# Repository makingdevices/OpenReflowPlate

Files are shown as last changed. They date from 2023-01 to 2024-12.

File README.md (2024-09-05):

<!-- Improved compatibility of back to top link: See: https://github.com/othneildrew/Best-README-Template/pull/73 -->

<!--
*** Thanks for checking out the Best-README-Template. If you have a suggestion
*** that would make this better, please fork the repo and create a pull request
*** or simply open an issue with the tag "enhancement".
*** Don't forget to give the project a star!
*** Thanks again! Now go create something AMAZING! :D
-->

<!-- PROJECT SHIELDS -->
<!--
*** I'm using markdown "reference style" links for readability.
*** Reference links are enclosed in brackets [ ] instead of parentheses ( ).
*** See the bottom of this document for the declaration of the reference variables
*** for contributors-url, forks-url, etc. This is an optional, concise syntax you may use.
*** https://www.markdownguide.org/basic-syntax/#reference-style-links
-->
[][ig-url]
[][sponsor-url]
[][stars-url]
[][issues-url]
[][linkedin-url]

<!-- PROJECT LOGO -->
<br />
<div align="center">
  <a href="https://makingdevices.com/links/">
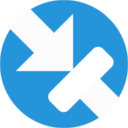
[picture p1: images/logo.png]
    
  </a>

<h3 align="center">Making Devices</h3>

  <p align="center">
    Open Source projects where we struggle with engineering, electronics, coding and who knows what else... In this case, OpenReflowPlate is a simple reflow plate for SMD PCBs, so hopefully you may find it interesting ;)
  </p>
</div>

<!-- TABLE OF CONTENTS -->
<details>
  <summary>Table of Contents</summary>
  <ol>
    <li>
      <a href="#about-the-project">About The Project</a>
      <ul>
        <li><a href="#built-with">Built With</a></li>
      </ul>
    </li>
    <li>
      <a href="#Build-one">Build one</a>
      <ul>
      </ul>
    </li>
    <li><a href="#usage">Usage</a></li>
    <li><a href="#roadmap">Roadmap</a></li>
    <li><a href="#license">License</a></li>
    <li><a href="#contact">Contact</a></li>
    <li><a href="#Sponsor">Sponsor</a></li>
  </ol>
</details>

<!-- ABOUT THE PROJECT -->
## About The Project

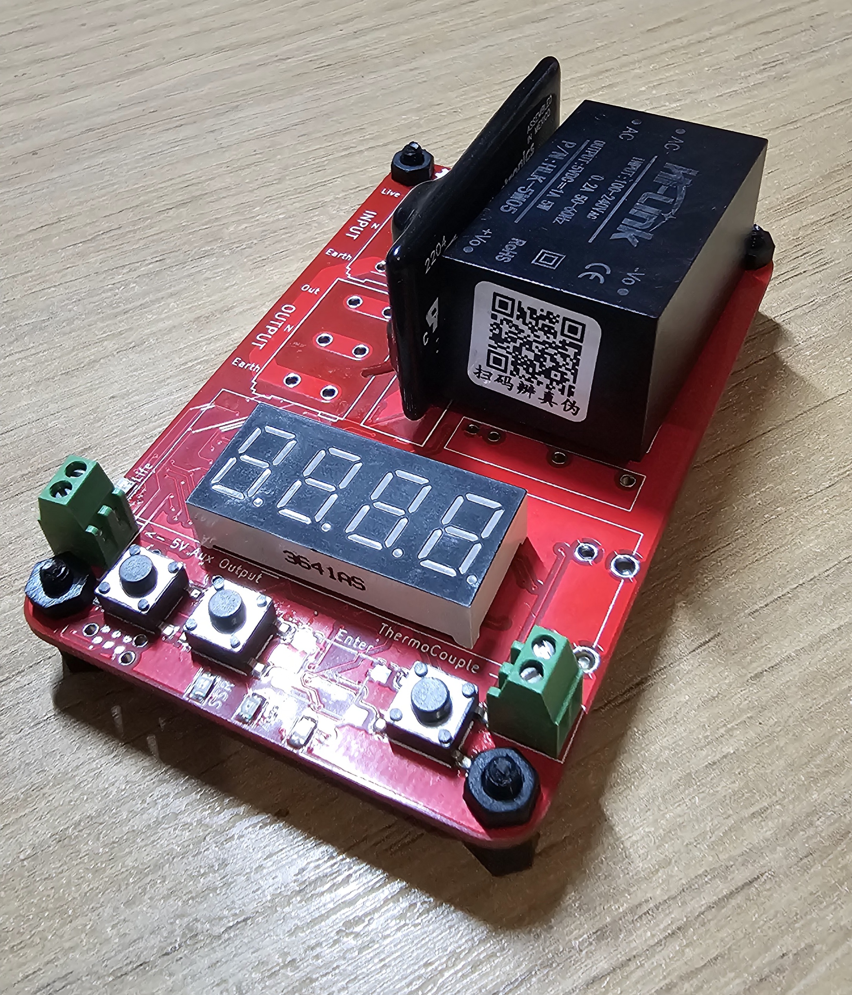
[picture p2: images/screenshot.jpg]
Bytes Counter Shot
[](https://github.com/makingdevices/OpenReflowPlate)

OpenReflowPlate wants to be a complete controller where you can attach to it any heat plate and create a reflowplate for SMD components and PCBs. Right now, it is in prototype stage as I do not even have a PCB layout, just testing the capabilities with an expansion board from my Thermo-Logger-Device project. The microcontroller will be the PIC18F45k50.

This device is under development, so I do encourage you to not assembly, order any PCB or use any software from this repository until the project is finished.

<p align="right">(<a href="#readme-top">back to top</a>)</p>

### Built With

[][PIC-url]
[][MPLAB-C-url]
[][kicad-url]
[][sponsor-url]

<p align="right">(<a href="#readme-top">back to top</a>)</p>

<!-- GETTING STARTED -->

## Build one
NOT RECOMMENDED AS THE DEVICE IS UNDER DEVELOPMENT

<p align="right">(<a href="#readme-top">back to top</a>)</p>

<!-- USAGE EXAMPLES -->
## Usage

Instructions of use:

- Only one MAX31855KASA is in use.
- I use the LED output to activate an SSR to control the heat plate.

<p align="right">(<a href="#readme-top">back to top</a>)</p>

<!-- ROADMAP -->
## Roadmap

- [ ] Validate the product with the expansion board and the thermo logger device.
- [ ] Finish the Python software to control the heatplate.
- [ ] Start/finish the new PCB
    - [ ] PIC18F45k50.
    - [ ] Add 8 segment display.
    - [ ] Add buttons for standalone mode.
    - [ ] Develop the PID strategy inside the firmware of the microcontroller.
    - [ ] Isolated USB communication to avoid any damage to the PC if in use. 
- [ ] Test/Validate the project.

See the [open issues](https://github.com/makingdevices/OpenReflowPlate/issues) for a full list of proposed features (and known issues).

State: Project <b>UNFINISHED</b> - 06/01/2023

<p align="right">(<a href="#readme-top">back to top</a>)</p>

<!-- LICENSE -->
## License

Distributed under three licenses:
- [Hardware](/License/HW_cern_ohl_s_v2.pdf)
- [Software](/License/SW_GPLv3.0.txt)
- [Documentation](/License/Documentation_CC-BY-SA-4.0.txt)

[GPL v3 License][license-url] 
<p align="right">(<a href="#readme-top">back to top</a>)</p>

<!-- CONTACT -->
## Contact

Making Devices - [@MakingDevices](https://www.instagram.com/makingdevices/)

Project Link: [https://github.com/makingdevices/OpenReflowPlate](https://github.com/makingdevices/OpenReflowPlate/)

Other Links: [LinkTree](https://makingdevices.com/links/)

<p align="right">(<a href="#readme-top">back to top</a>)</p>

## Sponsor

[PCBWAY](https://www.pcbway.com/?from=makingdevices) is the most professional PCB manufacturer for prototyping and low-volume production to work with in the world. With more than a decade in the field, They are committed to meeting the needs of their customers from different industries in terms of quality, delivery, cost-effectiveness and any other demanding requests. As Sponsor of Making Devices, they will be in charge of all the PCBs for MDV, allowing both of us to grow together in a long term partnership. We hope you take them into account for your both personal and professional prototypes or products.

[![Sponsor Shot][sponsor-pcb-1]][sponsor-url]
[![Sponsor Shot][sponsor-pcb-2]][sponsor-url]

<!-- MARKDOWN LINKS & IMAGES -->
<!-- https://www.markdownguide.org/basic-syntax/#reference-style-links -->
[contributors-shield]: https://img.shields.io/github/contributors/makingdevices/OpenReflowPlate.svg?style=for-the-badge
[contributors-url]: https://github.com/makingdevices/OpenReflowPlate/graphs/contributors
[forks-shield]: https://img.shields.io/github/forks/makingdevices/OpenReflowPlate.svg?style=for-the-badge
[forks-url]: https://github.com/makingdevices/OpenReflowPlate/network/members
[stars-shield]: https://img.shields.io/github/stars/makingdevices/OpenReflowPlate.svg?style=for-the-badge
[stars-url]: https://github.com/makingdevices/OpenReflowPlate/stargazers
[issues-shield]: https://img.shields.io/github/issues/makingdevices/OpenReflowPlate.svg?style=for-the-badge
[issues-url]: https://github.com/makingdevices/OpenReflowPlate/issues
[license-shield]: /images/license.png
[license-url]: https://github.com/makingdevices/OpenReflowPlate/tree/main/License
[linkedin-shield]: https://img.shields.io/badge/-LinkedIn-black.svg?style=for-the-badge&logo=linkedin&colorB=555
[linkedin-url]: https://www.linkedin.com/company/making-devices/
[sponsor-shield]: https://img.shields.io/badge/SPONSOR-PCBWAY-black.svg?style=for-the-badge&colorB=1200
[sponsor-url]: https://www.pcbway.com/?from=makingdevices
[sponsor-screenshot]: /images/PCB_sponsor.png
[pcb_pic1]: images/openreflowplate_pcb1.jpg
[pcb_pic2]: images/openreflowplate_pcb2.jpg
[product-screenshot]: images/screenshot.jpg
[PIC]: https://img.shields.io/badge/PIC18LF45K50-000000?style=for-the-badge
[PIC-url]: http://ww1.microchip.com/downloads/en/devicedoc/40001350f.pdf
[kicad-shield]: https://img.shields.io/badge/kicad-0b03fc?style=for-the-badge&logo=kicad&logoColor=white
[kicad-url]: https://www.kicad.org/
[YT-screenshot]: images/YT_assembly.PNG
[sponsor-icon]:  https://img.shields.io/badge/-PCBWAY-black.svg?style=for-the-badge&colorB=1200
[ig-shield]: https://img.shields.io/badge/instagram-a83297?style=for-the-badge&logo=instagram&logoColor=white
[ig-url]: https://www.instagram.com/makingdevices/
[MPLAB-C]: https://img.shields.io/badge/MPLAB%20C18-DD0031?style=for-the-badge&logo=C&logoColor=white
[MPLAB-C-url]: https://www.microchip.com/en-us/development-tool/SW006011
[Svelte.dev]: https://img.shields.io/badge/Svelte-4A4A55?style=for-the-badge&logo=svelte&logoColor=FF3E00
[Svelte-url]: https://svelte.dev/
[Laravel.com]: https://img.shields.io/badge/Laravel-FF2D20?style=for-the-badge&logo=laravel&logoColor=white
[Laravel-url]: https://laravel.com
[Bootstrap.com]: https://img.shields.io/badge/Bootstrap-563D7C?style=for-the-badge&logo=bootstrap&logoColor=white
[Bootstrap-url]: https://getbootstrap.com
[JQuery.com]: https://img.shields.io/badge/jQuery-0769AD?style=for-the-badge&logo=jquery&logoColor=white
[JQuery-url]: https://jquery.com

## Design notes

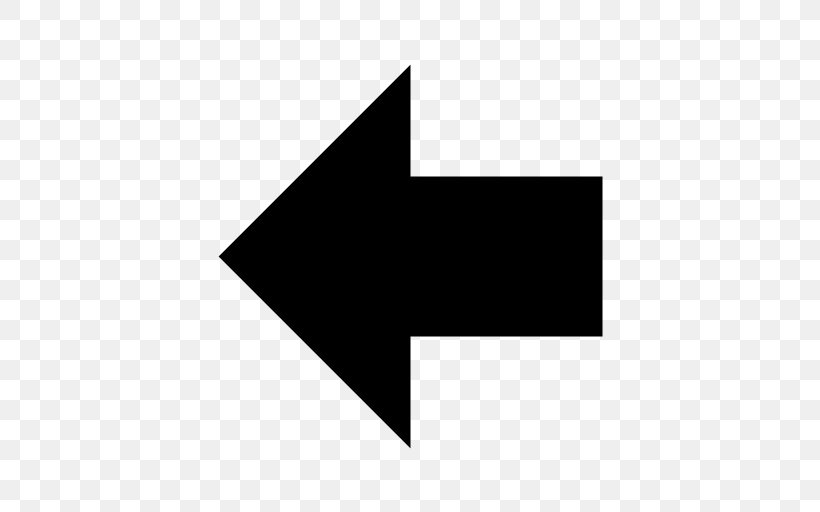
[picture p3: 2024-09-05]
images/arrow.jpg

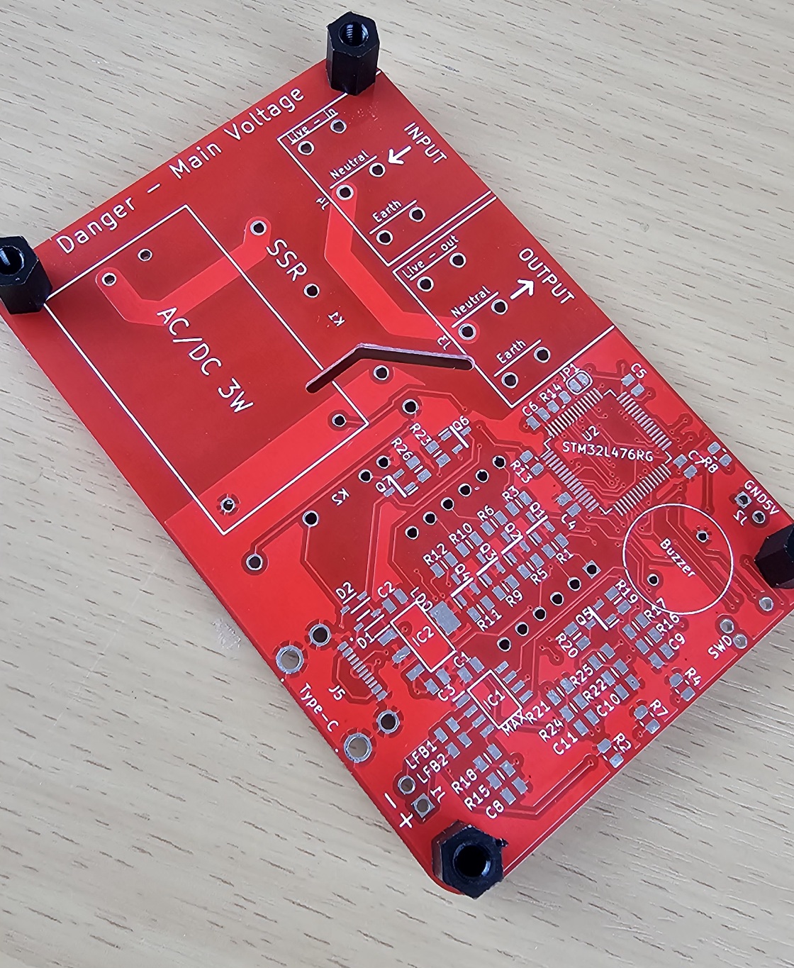
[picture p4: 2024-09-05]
images/openreflowplate_pcb2.jpg

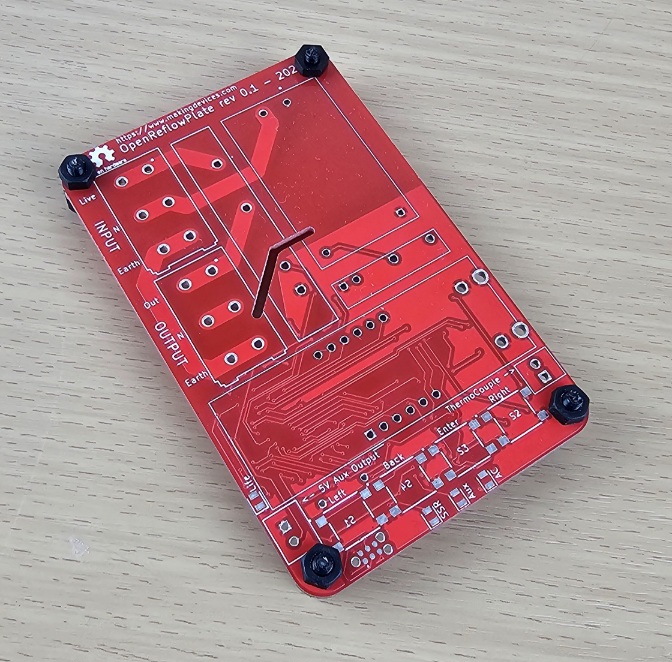
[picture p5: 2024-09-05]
images/openreflowplate_pcb1.jpg

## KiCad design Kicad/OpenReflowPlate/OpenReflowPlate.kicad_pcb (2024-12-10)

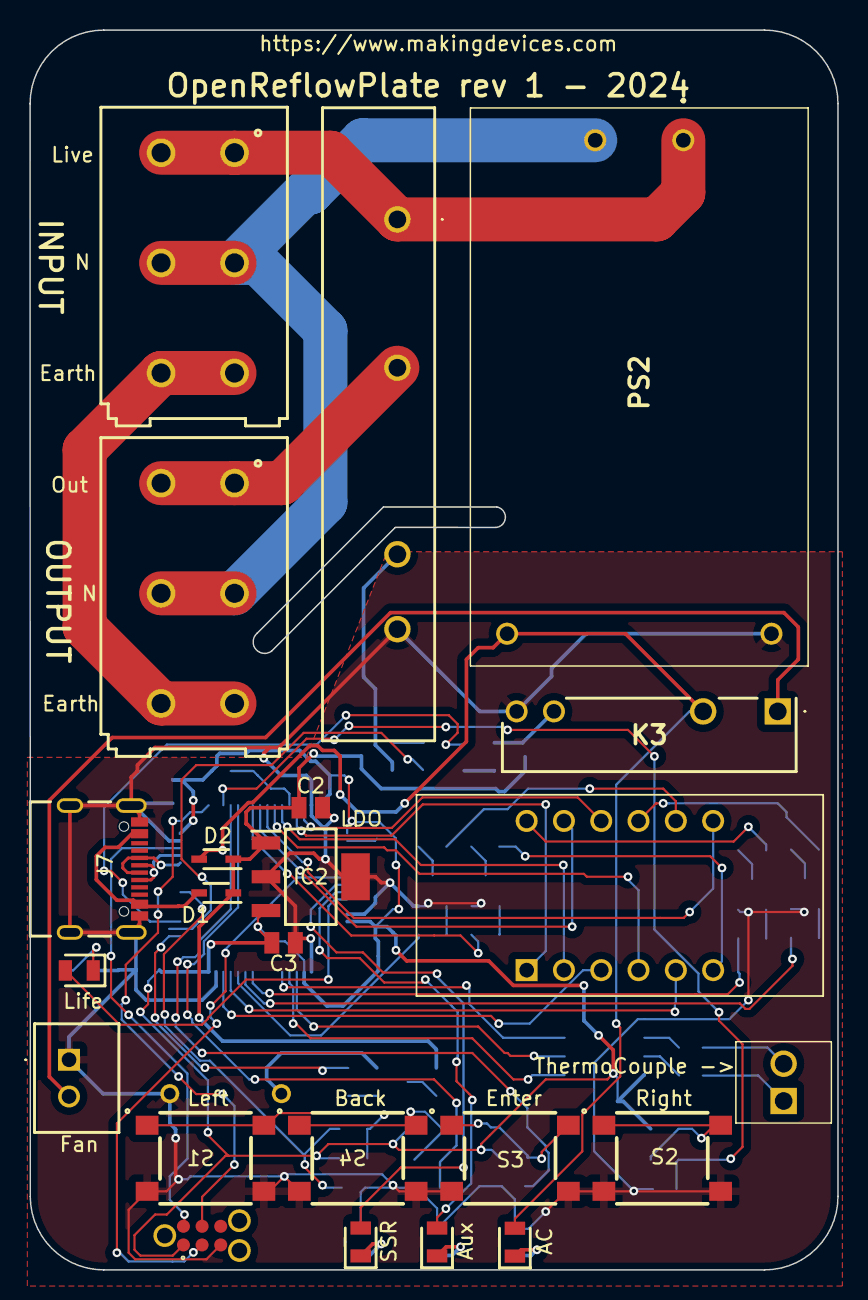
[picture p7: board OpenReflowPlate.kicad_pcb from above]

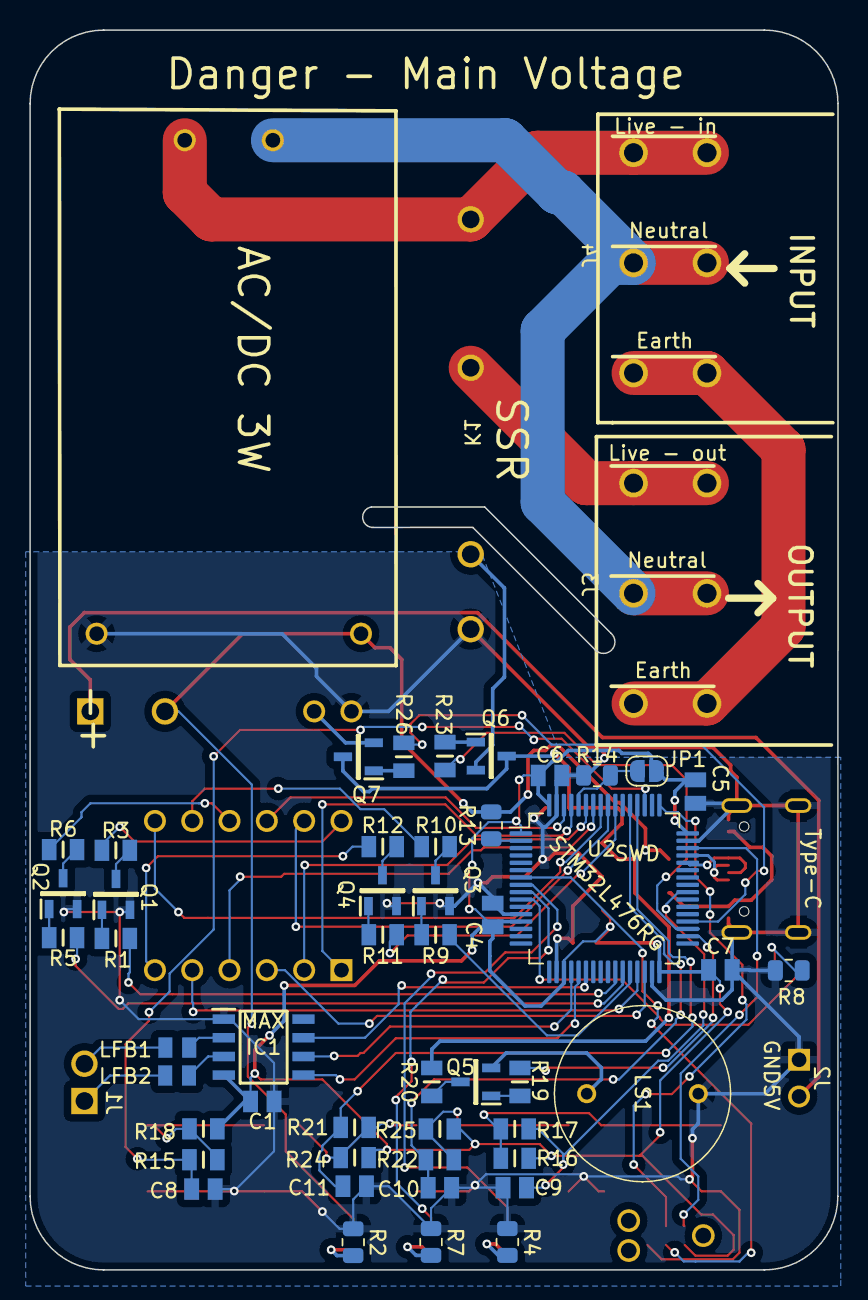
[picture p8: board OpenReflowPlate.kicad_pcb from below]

Board: 2 copper layers, 55.0 x 84.4 mm, 71 parts (48 on the bottom side), 73 nets.

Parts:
C1, C2, C3, C5, C6, C7: 100nF; CAPC2012X140N
C4: 4u7; CAPC2012X140N
C8, C9, C10, C11: 22pF; CAPC2012X140N
D1, D2: ZLLS410TA; SOD2513X120N
IC1: MAX31855KASA+; SOIC127P600X175-8N
IC2: TC1108-3.3VDBTR; SOT230P700X180-4N
J1: TC connector; 282834-2_1
J2: B2B-XH-A; B2BXHA
J3: Output_AC; 691411910003
J4: Input_AC; 691411910003
J6: TC2030-MCP-NL
J7: 629722000214
JP1: SolderJumper_2_Open; SolderJumper-2_P1.3mm_Open_RoundedPad1.0x1.5mm
K1: SSRC-240D5R; SSRC240D5R
K3: HF49FD_012-1H11F; HF49FD0121H11F
LED1, LED2, LED3, LED4: SML-H12V8TT86; LEDC2012X90N
LFB1, LFB2: Ferrite; CAPC2012X90N
LS1: TMB12A05
PS2: HLK-5M05; HLK5M05
Q1, Q2, Q3, Q4, Q5, Q6, Q7: SMMBT5551LT1G; SOT96P237X111-3N
R1, R5, R9, R11, R19, R23, R26: 4k7; RESC2012X65N
R2: 1k; R_0805_2012Metric
R3, R6, R10, R12: 100; RESC2012X65N
R4, R7, R8: 220; R_0805_2012Metric
R13: 0; R_0805_2012Metric
R14: 10K; R_0805_2012Metric
R15, R16, R22: 10k; RESC2012X75N
R17: 10K; RESC2012X65N
R18, R24, R25: 10k; RESC2012X65N
R20: 220; RESC2012X65N
R21: 10K; RESC2012X75N
S1: Left Button; 430182070816
S2: Right Button; 430182070816
S3: Enter Button; 430182070816
S4: Back Button; 430182070816
U1: CC56-12EWA; CA56-12EWA
U2: STM32L476RGTx; LQFP-64_10x10mm_P0.5mm

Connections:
+3V3: C1.1, C3.1, C4.2, C5.2, C6.2, C7.2, IC1.4 (VCC), IC2.3 (VOUT), J6.1 (-MCLR/VPP), JP1.1 (A), R16.2, R18.2, R24.2, R25.2, U2.1 (VBAT), U2.13 (VDDA), U2.19 (VDD), U2.32 (VDD), U2.48 (VDDUSB), U2.64 (VDD)
+5V: C2.1, D1.1, D2.1, IC2.1 (VIN), Q6.3, Q7.3, R20.1
AC_L: J4.1, J4.A1, K1.1 (AC_LOAD_1), PS2.1 (AC_1)
AC_N: J3.2, J3.A2, J4.2, J4.A2, PS2.2 (AC_2)
AC_Vdcin+: D2.2, K3.2 (NO), LED1.2, PS2.4 (+VO), R13.2
AC_ground: J3.3, J3.A3, J4.3, J4.A3
Activation_out1: K1.3 (+DC_INPUT), Q6.2
Activation_out2: K3.3 (COIL_1), Q7.2
BUT_BACK: C10.1, R22.1, U2.53 (PC12)
BUT_ENTER: C11.1, R21.1, U2.52 (PC11)
BUT_LEFT: C9.2, R17.2, U2.40 (PC9)
BUT_RIGHT: C8.1, R15.1, U2.51 (PC10)
CC_1: R3.2, U1.12 (CC1)
CC_2: R6.2, U1.9 (CC2)
CC_3: R10.2, U1.8 (CC3)
CC_4: R12.2, U1.6 (CC4)
C_1: R1.1, U2.26 (PB0)
C_2: R5.1, U2.27 (PB1)
C_3: R9.1, U2.28 (PB2)
C_4: R11.1, U2.55 (PB3)
C_buzzer: R19.1, U2.34 (PB13)
C_out1: R23.1, U2.35 (PB14)
C_out2: R26.1, U2.36 (PB15)
DC_Out2: J2.2, K3.1 (COM)
D_a: U1.11 (a), U2.56 (PB4)
D_b: U1.7 (b), U2.57 (PB5)
D_c: U1.4 (c), U2.58 (PB6)
D_d: U1.2 (d), U2.59 (PB7)
D_dp: U1.3 (DPX), U2.30 (PB11)
D_e: U1.1 (e), U2.61 (PB8)
D_f: U1.10 (f), U2.62 (PB9)
D_g: U1.5 (g), U2.29 (PB10)
GND: C1.2, C2.2, C3.2, C4.1, C5.1, C6.1, C7.1, C8.2, C9.1, C10.2, C11.2, IC1.1 (GND), IC2.2 (GND_1), IC2.4 (GND_2), J2.1, J6.5 (PGC_(ICSPCLK)), J7.A1 (GND), J7.A12 (GND1), J7.B1 (GND3), J7.B12 (GND2), J7.S1, J7.S2, J7.S3, J7.S4, K1.4 (_-DC_INPUT), K3.4 (COIL_2), LS1.2 (-), PS2.3 (-VO), Q1.2, Q2.2, Q3.2, Q4.2, R2.1, R4.1, R7.1, R8.1, R14.1, S1.2, S1.4, S2.2, S2.4, S3.2, S3.4, S4.2, S4.4, U2.12 (VSSA), U2.18 (VSS), U2.31 (VSS), U2.47 (VSS), U2.63 (VSS)
LED_LIFE: LED4.2, U2.10 (PC2)
LED_OUT1: LED2.2, U2.8 (PC0)
LED_OUT2: LED3.2, U2.9 (PC1)
unnamed: IC1.3 (T+), LFB2.2
unnamed: IC1.2 (T-), LFB1.2
unnamed: J1.1, LFB2.1
unnamed: J1.2, LFB1.1
unnamed: JP1.2 (B), R14.2, U2.60 (BOOT0)
unnamed: J3.1, J3.A1, K1.2 (AC_LOAD_2)
unnamed: LED1.1, R2.2
unnamed: LED2.1, R4.2
unnamed: LED3.1, R7.2
unnamed: LED4.1, R8.2
unnamed: LS1.1 (+), Q5.2
unnamed: Q1.1, R1.2
unnamed: Q1.3, R3.1
unnamed: Q2.1, R5.2
unnamed: Q2.3, R6.1
unnamed: Q3.1, R9.2
unnamed: Q3.3, R10.1
unnamed: Q4.1, R11.2
unnamed: Q4.3, R12.1
unnamed: Q5.1, R19.2
unnamed: Q5.3, R20.2
unnamed: Q6.1, R23.2
unnamed: Q7.1, R26.2
unnamed: R15.2, R18.1, S2.1, S2.3
unnamed: R16.1, R17.1, S1.1, S1.3
unnamed: R21.2, R24.1, S3.1, S3.3
unnamed: R22.2, R25.1, S4.1, S4.3
unnamed: R13.1, U2.2 (PC13)
SPI1_NSS: IC1.6 (~CS), U2.20 (PA4)
SPI_CLK: IC1.5 (SCK), U2.21 (PA5)
SPI_MISO: IC1.7 (SO), U2.22 (PA6)
SWCLK: J6.4 (PGD_(ICSPDAT)), U2.49 (PA14)
SWDIO: J6.2 (VDD), U2.46 (PA13)
USB_D+: J7.A6 (D+1), J7.B6 (D+2), U2.45 (PA12)
USB_D-: J7.A7 (D-1), J7.B7 (D-2), U2.44 (PA11)
USB_Vin+: D1.2, J7.A4 (VBUS), J7.A9 (VBUS1), J7.B4 (VBUS3), J7.B9 (VBUS2)
reset: J6.3 (GND), U2.7 (NRST)

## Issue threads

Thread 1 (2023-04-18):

[0.1] Component selection

makingdevices, 2023-04-18:
Component selection:

- [ ] **Microcontroller:** ST32 [TBD]
- [ ] **Display:** 8 segment 4 digit display.
- [ ] **Temperature Sensor:** MAX31855
- [ ] **SSR:** TE
- [ ] **Relay:** ?

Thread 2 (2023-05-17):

Input control

makingdevices, 2023-05-17:
The device should have at least four buttons to navigate in the menu and options. The temperature can be settled by them as well.

**Design: **

- [ ] Four push generic buttons

**Validate: **

- [ ] They are used to navigate in the options and menu

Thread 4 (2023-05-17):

Heatbed

makingdevices, 2023-05-17:
The device should have a 10cmx20cm heatplate with a temperature reading and PI control. The maximum temperature will reach at least 250ºC

**Design:**

- [ ] AC heatbed 10cmx20cm 500W
- [ ] MAX31855 thermocouple ADC
- [ ] ST32F446RE as main brain to operate the PI(D) control

**Validate:**

- [ ] The temperature can be controlled with an error of +-5ºC

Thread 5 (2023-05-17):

Operation Modes

makingdevices, 2023-05-17:
The device should have at least the following modes:

1. Fix temperature (by user)
2. Reflow curve profile (Predefined)
3. Remote Control (USB Protocol)

**Design:**

- [ ] The modes can be changed with the use of the buttons.

**Validate:**

- [ ] All modes work as expected

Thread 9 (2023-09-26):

Assembly First Iteration

makingdevices, 2023-09-26:
The first iteration of the PCB should be assembled to test if everything works as intended

**Design:**
- [ ] Release v0.1 PCB Version.
- [ ] Order & Receive PCBs.
- [ ] Assembly v0.1 PCB Version.

**Validate:**
- [ ] The PCB has no problems or errors in the footprints and all the components are in stock.

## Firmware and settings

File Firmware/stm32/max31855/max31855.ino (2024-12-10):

#define TIMER_INTERRUPT_DEBUG         0
#define _TIMERINTERRUPT_LOGLEVEL_     0

#include "STM32TimerInterrupt.h"
#include "STM32_ISR_Timer.h"
// inslude the SPI library:
#include <SPI.h>
#include <SoftwareSerial.h>

#define TIMER_INTERVAL_MS         100
#define HW_TIMER_INTERVAL_MS      50

// Init STM32 timer TIM1
STM32Timer ITimer(TIM1);

// Init STM32_ISR_Timer
// Each STM32_ISR_Timer can service 16 different ISR-based timers
STM32_ISR_Timer ISR_Timer;

#define TIMER_INTERVAL_0_50mS         1L
#define TIMER_INTERVAL_0_5S           500L
#define TIMER_INTERVAL_1S             1000L
#define TIMER_INTERVAL_1_5S           1500L
#define DELAYVAL 500

//For display:
int digit_display = 0; //Display digit at the moment 
char const vector[] = {0b00111111,0b00000110,0b01011011,0b01001111,0b01100110,0b01101101,0b01111101,0b00000111,0b01111111,0b01100111,0b001000000,0b01111001}; //Numbers 8-segment codification
char const vector_menu[3][4] = {{0b01101101,0b00111111,0b00111000,0b00111111},{0b01110111,0b00011100,0b00110001,0b00111111},{0b01000000,0b01110011,0b00111001,0b01000000}};  // SOLO, AUTO, PC
int number_display[] = {0,0,0,0}; //Number Storage
int temperature = 0;

// set pin 10 as the slave select for the digital pot:
const int slaveSelectPin = PA4;
const int led_life = PC2;
const int bt_left = PC9;
const int bt_right = PC10;
const int bt_back = PC12;
const int bt_enter = PC11;
const int displayPins[] = {PB4,PB5,PB6,PB7,PB8,PB9,PB10,PB11};
int mode = 0; // 0 = menu, 1 = activated
int menu = 0; // 0 = FIX, 1 = AUTO, 2 = PC.
int menu_lvl = 0; // 0 first lvl, 1 to set temperature

void TimerHandler()
{
  ISR_Timer.run();
}

void inttotemp(int temp){
  number_display[3] = temp % 10;
  number_display[2] = (temp / 10) % 10;
  number_display[1] = (temp / 100) % 10;
  number_display[0] = (temp / 1000) % 10;
}

int nr_digit(int digit){
  		switch(digit){  //Print the numbers over the display
			case 3:		//we light the correct display
				digitalWrite(PB0, LOW);
        digitalWrite(PB1, LOW);
        digitalWrite(PB2, LOW);
        digitalWrite(PB3, HIGH);
				digit = 0;
				break;
			case 0:
				digitalWrite(PB0, HIGH);
        digitalWrite(PB1, LOW);
        digitalWrite(PB2, LOW);
        digitalWrite(PB3, LOW);
				digit = 1;
				break;
			case 1:
				digitalWrite(PB0, LOW);
        digitalWrite(PB1, HIGH);
        digitalWrite(PB2, LOW);
        digitalWrite(PB3, LOW);
				digit = 2;
				break;
			case 2:
				digitalWrite(PB0, LOW);
        digitalWrite(PB1, LOW);
        digitalWrite(PB2, HIGH);
        digitalWrite(PB3, LOW);
				digit = 3;
				break;
			default:
				break;
		}
    return digit;
}

void print_display(int number){
  for(int i=0;i<8;i++) {
    digitalWrite(displayPins[i], (vector[number]&(0b00000001<<i))>>i);
  }
}

void print_menu_display(int number){
  for(int i=0;i<8;i++) {
    digitalWrite(displayPins[i], (vector_menu[menu-1][number]&(0b00000001<<i))>>i);
  }
}

int buttonstate = 0;  // variable for reading the pushbutton status
void TimerInterrupt()
{
  if(mode==1 || (mode==0 && menu == 0)){
    inttotemp(temperature);
    print_display(number_display[digit_display]);
  } else {
    print_menu_display(digit_display);
  }
  digit_display = nr_digit(digit_display);

  if(digitalRead(bt_right) == LOW && buttonstate==0){
    buttonstate=1;
    if(menu_lvl==0 && menu < 3) menu++;
    else if(menu_lvl==0) menu = 0;
  }
  if(digitalRead(bt_left) == LOW && buttonstate==0){
    buttonstate=1;
    if(menu_lvl==0 && menu > 0) menu--;
    else if(menu_lvl==0) menu = 3;
  }
  if(digitalRead(bt_back) == LOW && buttonstate==0){
    buttonstate=1;
    menu = 0;
  }
  if(digitalRead(bt_right) == HIGH && digitalRead(bt_left) == HIGH && digitalRead(bt_back) == HIGH){
    buttonstate=0;
  }
}
// Create a new SPI port with:
// Pin 2 = MOSI,
// Pin 3 = MISO,
// Pin 4 = SCK
// Set up a new SoftwareSerial object
void setup() {
  // open the serial port at 9600 bps:
  //Serial.begin(9600);
  
  SPI.begin();
  // set the slaveSelectPin as an output:
  pinMode(slaveSelectPin, OUTPUT);
  pinMode(PB0, OUTPUT);
  pinMode(PB1, OUTPUT);
  pinMode(PB2, OUTPUT);
  pinMode(PB3, OUTPUT);
  pinMode(PB14, OUTPUT);
  pinMode(PB15, OUTPUT);

  pinMode(bt_left, INPUT);
  pinMode(bt_right, INPUT);
  pinMode(bt_back, INPUT);
  pinMode(bt_enter, INPUT);
  
  for(int i=0;i<8;i++) {
    pinMode(displayPins[i], OUTPUT);
  }
  pinMode(led_life, OUTPUT);
  // Interval in microsecs
  if (ITimer.attachInterruptInterval(HW_TIMER_INTERVAL_MS * 100, TimerHandler))
  {
    
  }

  // Just to demonstrate, don't use too many ISR Timers if not absolutely necessary
  // You can use up to 16 timer for each ISR_Timer
  ISR_Timer.setInterval(TIMER_INTERVAL_0_50mS,  TimerInterrupt);
}

int incomingByte = 0;
void loop() {
  // go through the six channels of the digital pot:
  temperature = MAX31855K();
  delay(DELAYVAL);
  digitalWrite(led_life, !digitalRead(led_life));
  digitalWrite(PB14, HIGH);
  digitalWrite(PB15, HIGH);
  //Serial.print(" External_temp: ");
  //Serial.println(temperature);
}

int MAX31855K(void) {
  int var1=0, var2=0, var3=0, var4=0, var5= 0;
  double external_temp = 0;
  double internal_temp = 0;

  // take the SS pin low to select the chip:
  digitalWrite(slaveSelectPin, LOW);
  delay(500);
  var1 = SPI.transfer(0xFF);
  var2 = SPI.transfer(0xFF);
  var3 = SPI.transfer(0xFF);
  var4 = SPI.transfer(0xFF);
  var5 = SPI.transfer(0xFF);
  // take the SS pin high to de-select the chip:
  digitalWrite(slaveSelectPin, HIGH);
  /*
  Serial.println("Let's begin");
  Serial.println(var1);
  Serial.println(var2);
  Serial.println(var3);
  Serial.println(var4);
  Serial.println(var5);
*/
  internal_temp = (var3<<4) | (var4&0xF0)>>4;
  internal_temp = internal_temp*0.0625;
  external_temp = var1<<6 | (var2&0b11111100)>>2;
  external_temp = external_temp * 0.25;

  return external_temp;
}

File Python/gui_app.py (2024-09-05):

### Reflow Oven prototype software
## Making Devices - Q4 2022 
#

import sys, time
from PyQt5 import uic, QtCore
from PyQt5.QtCore import QThread
import matplotlib.pyplot as plt
from PyQt5.QtWidgets import QMainWindow, QApplication
import serial.tools.list_ports
from simple_pid import PID

import serial, time

COMS = []

def bin2tempint(binary, binary2):
    temperature = 0
    if(binary&0b00000001 == 1):
        print("thermocouple is open circuit")
    elif(binary&0b00000010 == 0b10):
        print("thermocouple is short-circuit to GND")
    elif(binary&0b00000100 == 0b100):
        print("thermocouple is short-circuit to Vcc")
    if(binary&0b00010000 == 0b10000):
        temperature += 0.0625
    if(binary&0b00100000 == 0b100000):
        temperature += 0.125
    if(binary&0b01000000 == 0b1000000):
        temperature += 0.25
    if(binary&0b10000000 == 0b10000000):
        temperature += 0.5
    if(binary2&0b0000001 == 0b1):
        temperature += 1
    if(binary2&0b0000010 == 0b10):
        temperature += 2
    if(binary2&0b00000100 == 0b100):
        temperature += 4
    if(binary2&0b00001000 == 0b1000):
        temperature += 8
    if(binary2&0b00010000 == 0b10000):
        temperature += 16
    if(binary2&0b00100000 == 0b100000):
        temperature += 32
    if(binary2&0b01000000 == 0b1000000):
        temperature += 64
    if(binary2&0b10000000 == 0b10000000):
        temperature = temperature*(-1)
    return temperature

def bin2tempext(binary, binary2):
    temperature = 0
    if(binary&0b00000001 == 1):
        print("Thermocouple error")
    if(binary&0b00000100 == 0b100):
        temperature += 0.25
    if(binary&0b00001000 == 0b1000):
        temperature += 0.5
    if(binary&0b00010000 == 0b10000):
        temperature += 1
    if(binary&0b00100000 == 0b100000):
        temperature += 2
    if(binary&0b01000000 == 0b1000000):
        temperature += 4
    if(binary&0b10000000 == 0b10000000):
        temperature += 8
    if(binary2&0b0000001 == 0b1):
        temperature += 16
    if(binary2&0b0000010 == 0b10):
        temperature += 32
    if(binary2&0b00000100 == 0b100):
        temperature += 64
    if(binary2&0b00001000 == 0b1000):
        temperature += 128
    if(binary2&0b00010000 == 0b10000):
        temperature += 256
    if(binary2&0b00100000 == 0b100000):
        temperature += 512
    if(binary2&0b01000000 == 0b1000000):
        temperature += 1024
    if(binary2&0b10000000 == 0b10000000):
        temperature = temperature*(-1)
    return temperature

# -------------------------
#   TASK CONTROL   --   VARIABLES GLOBALES
# -------------------------
event = '_IDLE_'
Loop_number = 0
out_setpoint = 25
out_status = 0
tc1_internal = 0
tc1_external = 0
x_axis = 100
interrupt_data = 0
tic = 0
toc = 0
tic_sample = 0
toc_sample = 0
comport = ""
connection_avail = 0
init_time = 0
new_cycle = 0
cycle_time = 0
device = serial.Serial()
start_time = 0
pid = PID(18, 1.6, 30, setpoint=out_setpoint)
last_time = 0
power = 0
windowStartTime = 0
## ---------------------------
##  GRAPH CLASS & RELATED DEFINITIONS
## ---------------------------

class BlitManager:
    def __init__(self, canvas, animated_artists=()):
        """
        Parameters
        ----------
        canvas : FigureCanvasAgg
            The canvas to work with, this only works for sub-classes of the Agg
            canvas which have the `~FigureCanvasAgg.copy_from_bbox` and
            `~FigureCanvasAgg.restore_region` methods.

        animated_artists : Iterable[Artist]
            List of the artists to manage
        """
        self.canvas = canvas
        self._bg = None
        self._artists = []

        for a in animated_artists:
            self.add_artist(a)
        # grab the background on every draw
        self.cid = canvas.mpl_connect("draw_event", self.on_draw)

    def on_draw(self, event):
        """Callback to register with 'draw_event'."""
        cv = self.canvas
        if event is not None:
            if event.canvas != cv:
                raise RuntimeError
        self._bg = cv.copy_from_bbox(cv.figure.bbox)
        self._draw_animated()

    def add_artist(self, art):
        """
        Add an artist to be managed.

        Parameters
        ----------
        art : Artist

            The artist to be added.  Will be set to 'animated' (just
            to be safe).  *art* must be in the figure associated with
            the canvas this class is managing.

        """
        if art.figure != self.canvas.figure:
            raise RuntimeError
        art.set_animated(True)
        self._artists.append(art)

    def _draw_animated(self):
        """Draw all of the animated artists."""
        fig = self.canvas.figure
        for a in self._artists:
            fig.draw_artist(a)

    def update(self):
        """Update the screen with animated artists."""
        cv = self.canvas
        fig = cv.figure
        # paranoia in case we missed the draw event,
        if self._bg is None:
            self.on_draw(None)
        else:
            # restore the background
            cv.restore_region(self._bg)
            # draw all of the animated artists
            self._draw_animated()
            # update the GUI state
            cv.blit(fig.bbox)
        # let the GUI event loop process anything it has to do
        cv.flush_events()

# ----------------------------------
#   USB Serial Check
# ----------------------------------

def serial_ports():
    """ Lists serial port names, descriptions and HW IDs
    """
    ports_avail = []
    ports = serial.tools.list_ports.comports()
    for port, desc, hwid in sorted(ports):
        if(hwid[12:16] == "04D8" and hwid[17:21] == "00AA"):
            ports_avail.append(port)
    return ports_avail

# ----------------------------------
#   GUI CLASS & RELATED DEFINITIONS
# ----------------------------------
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

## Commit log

2024-01-04 Rev 0.1
    [OpenReflowPlate.kicad_pcb, OpenReflowPlate.kicad_sch, OpenReflowPlate.sch]
2024-09-05 last version
    [OpenReflowPlate-B_Cu.gbr, OpenReflowPlate-B_Mask.gbr, OpenReflowPlate-B_Paste.gbr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]
2024-09-05 New PCBs!
2024-12-10 V1 HW
    [OpenReflowPlate-B_Cu.gbr, OpenReflowPlate-B_Mask.gbr, OpenReflowPlate-B_Paste.gbr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]
